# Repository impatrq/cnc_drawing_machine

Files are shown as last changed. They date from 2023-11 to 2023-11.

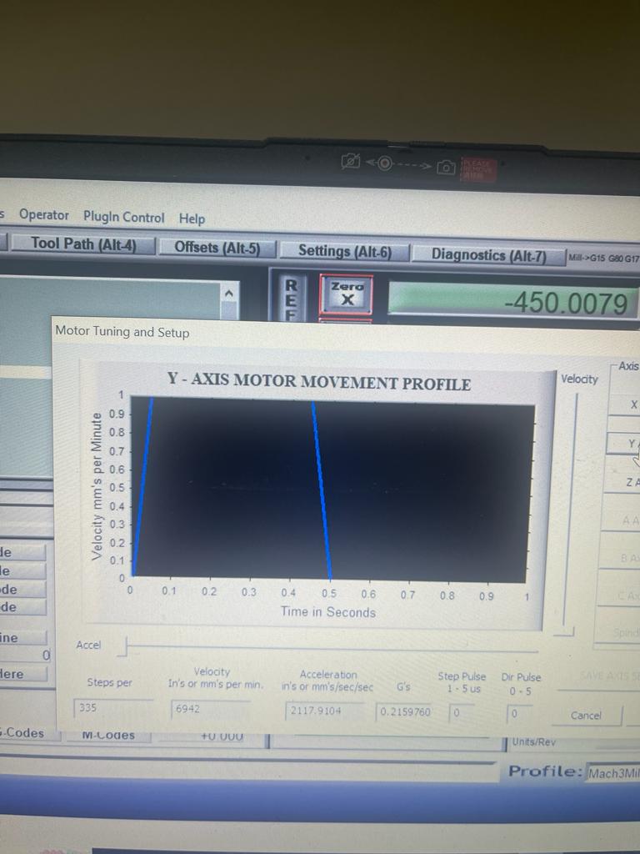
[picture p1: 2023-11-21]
Calibracion Motores Mach3/eje_y_calibration.jpg

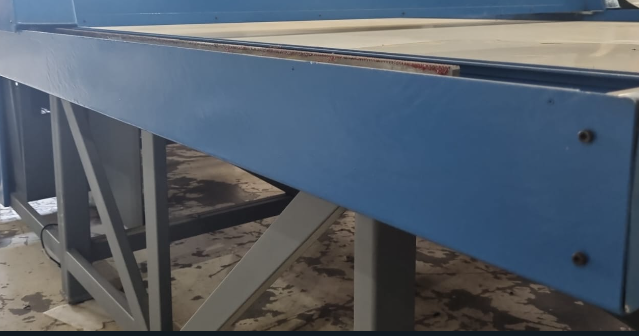
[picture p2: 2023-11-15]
Restauración/Proteccion de Rieles/PLACAS POSTERIORES DE RIELES RESTAURADAS.png

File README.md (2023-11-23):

<div align="center">

# CNC Miliing Machine 



<div align="left">

| Contactanos |
|------------|
|Email: cncproject2023@gmail.com |
|Instagram: cnc_project23 |
|LinkeDIn: Cnc Milling Machine Impa 2023 |
|Pagina Web: https://martincabrera162.wixsite.com/cnc-milling-project |

## ¿Qué es CNC?

CNC Milling Machine: CNC significa control numerico por computadora, es decir que es capaz de medir, automatizar y controlar sus propios procesos, esta siendo una Maquina el cual su obejtivo es cortar, grabar y fresar en madera y aluminio

## Como funciona CNC

El funcionamiento de la CNC es un proceso simple de entender pero a su vez complejo, este tiene como base el programa Mach3, subimos un archivo tipo DXF y R12 el cual, se puede llegar a vizaulisar en el progama como se veria, una vez subida la imagen, solo se debera configurar los limite o punto 0, una vez concretado el punto el progama se encarga de dar las instrucciones necesarias para el marcado o fresasdo de la maquina, una vez dada la instrucciones la maquina solo se encarga de hacer grabado, cortado o fresado para la imagen puesta.

## Infrastuctura/materiales Utilizados 

La CNC tiene una infraestructura muy resistente y de buena calidad. La mayor parte de la infraestructura estaba en optimas condiciones de uso y con poco rasgos de daños al principio del año cuando iniciamos el proyecto.
La infraeestructura de la CNC esta en su mayoria diseñada por la empresa Zucamor, el soporte hecho de metal solido, la mesa construida tambien por metal, con sus respectivos guias lineales para cada eje.
Nuestro principal trabajo fue la restauracion,deteccion y mantenimiento de partes dañadas, ya se diseñando nuevas partes o la reparacion de estas para su futuro uso. Ademas de darle una nueva vida a la CNC con pintura antioxidante para conservar su color y darle una nueva cara a la maquina.

## ¿Quienes somos?

Somos un grupo de alumnos de E.E.S.T. N°7 "Taller Regional Quilmes" (IMPA) de la Especialidad de Tecnico Avionico

### Cejas ramiro agustin

DNI: 46.030.174 

✆ 11 5946-8614

--> 📧 Ramiroagustincejas@gmail.com

Linkedin: www.linkedin.com/in/ramiro-cejas-20350629a

### Cabrera martin tadeo 

DNI: 45.812.906 

✆ 11 2260-3241

--> 📧 martincabrera14@hotmail.com

Linkedin: https://www.linkedin.com/in/martin-cabrera-2213b429a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

### Amarilla Joaquin 

DNI: 46.701.344 

✆ 11 4400-3314

--> 📧 joa.amarillos@gmail.com

Linkedin: https://www.linkedin.com/in/joaquin-amarilla-906a54173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

### Comisso Valentin

DNI: 46.428.455 

✆ 11 5931-8106

--> 📧 comissovalentin@gmail.com

Linkedin:

### Di virgilio Ivan

DNI: 46.740.367 

✆ 11 5812-7218

--> 📧 diviiva02@gmail.com

Linkedin: https://www.linkedin.com/in/ivan-di-virgilio-05bb202a0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

### Romero Tomas 

DNI: 46.904.673 

✆ 11 2158-7226

--> 📧 rometomy@gmail.com

Linkedin: https://www.linkedin.com/in/tomas-romero-a1938329a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

<div align="center">
 


 ## Como Contactarnos

<div align="left">

* 📧 Email: cncproject2023@gmail.com

* 🌐 Página Web: https://martincabrera162.wixsite.com/cnc-milling-project

* 📷 Instagram: @cnc_project23

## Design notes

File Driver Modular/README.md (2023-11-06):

## Configuracion del Driver Modular Tb6600

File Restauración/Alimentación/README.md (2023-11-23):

# Un antes y despues del gabinete con el circuito adentro

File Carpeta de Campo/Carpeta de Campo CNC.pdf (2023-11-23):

### Carpeta de campo

(Resumen de las cosas hechas día por día)

Participantes del proyecto CNC (Control Numérico por Computadora):

Martin Cabrera

Ivan Divirgilio

Tomas Romero

Ramiro Cejas

Joaquín Amarilla

Valentín Comisso

Dia 20 de marzo: Se nos dio el proyecto en el estado el cual nosotros debíamos cambiarlo, para esto en el mismo día movimos entre todos los participantes del proyecto, algunos profesores y otros alumnos el proyecto a una zona el cual podíamos estar más al alcance como también era más visible.

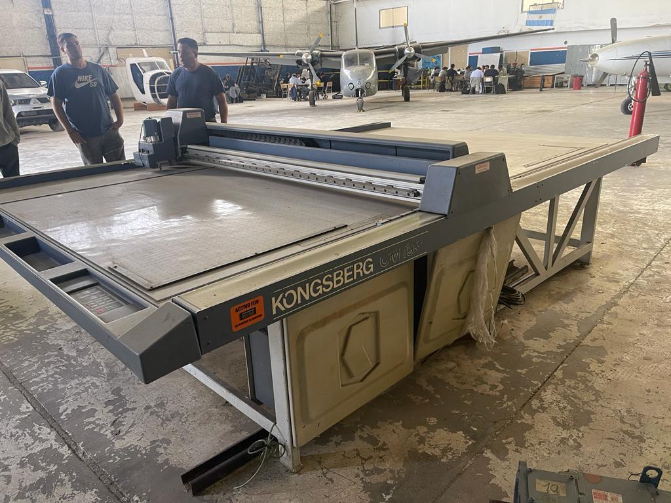
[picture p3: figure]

Semana del 20 hasta 27 de marzo: Se revisó la máquina de punta a punta, viendo que era lo que servía del proyecto, como los cables, las correas, los servos motores, las correderas o la estructura de la máquina y ver si no estaba quemado o en mal estado. Nos percatamos de que el equipo que poseía la maquina estaba muy desgastado, desactualizado y sin uso desde hace mucho.

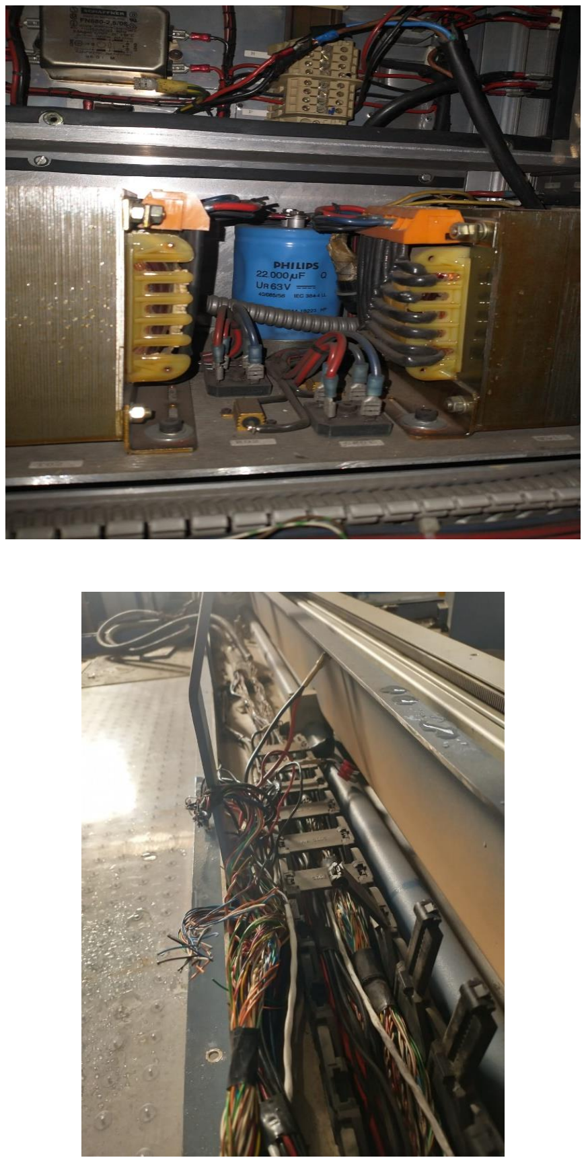
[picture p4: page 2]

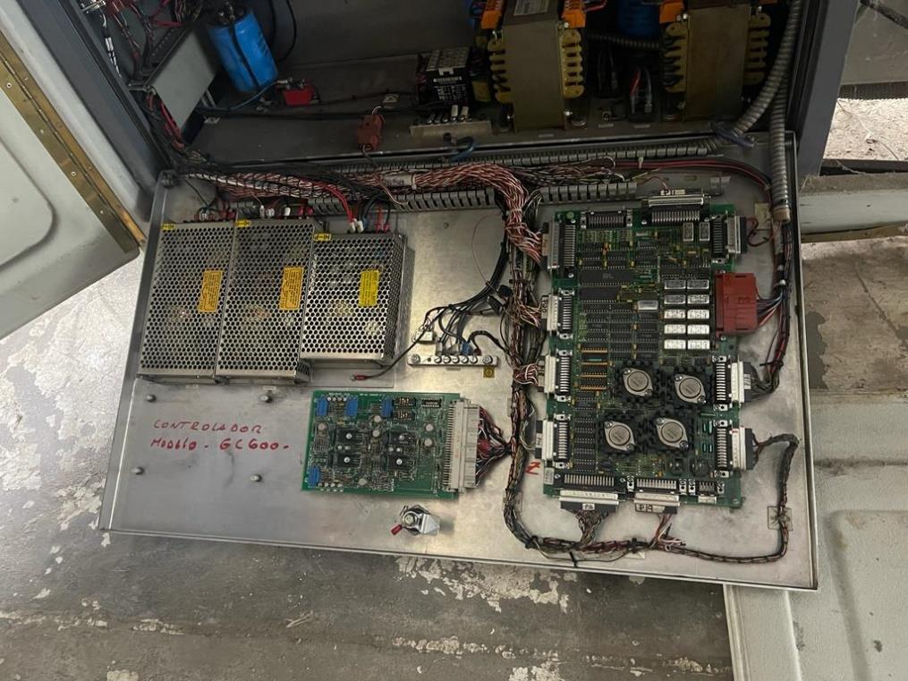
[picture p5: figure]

Dia 28, 29 y 30 de marzo: Se investigó bien cada material que teníamos en buen estado, buscando su datasheet, y toda propiedad de los materiales, para ver si cada cosa era compatible una con la otra, y si se necesitaba cambiar o agregar cosas. La investigación consistió en buscar la datasheet de los motores y sus drivers, como también si los paso a paso que tenían eran compatibles.

Dia 4 y 5 de abril: Se investigó sobre los softwares que se podían utilizar para los motores que necesitábamos, y ver si estos eran compatibles con los drivers que requeríamos.

Dia 11, 12 Y 13 de abril: Investigación sobre los encoder y sus señales de salida y, de entrada, al igual que sus motores, aunque por más que teníamos el encoder, decidimos comprar un paso a paso tanto por los beneficios y por qué el encoder tenía desperfectos que perjudicaban bastante al motor.

Dia 18, 19 y 20 de abril: Se investigó sobre los sensores que tenía la máquina, uno de los sensores que nos llamó la atención fueron los sensores sick, estos sensores de contraste eran una de las implementaciones que queremos poner.

Dia 25, 26 y 27 de abril: Se probó el motor para ver si recibía y funcionaba al 100%, como también visualizamos el conexionado de los drivers al rotor y estator de este mismo.

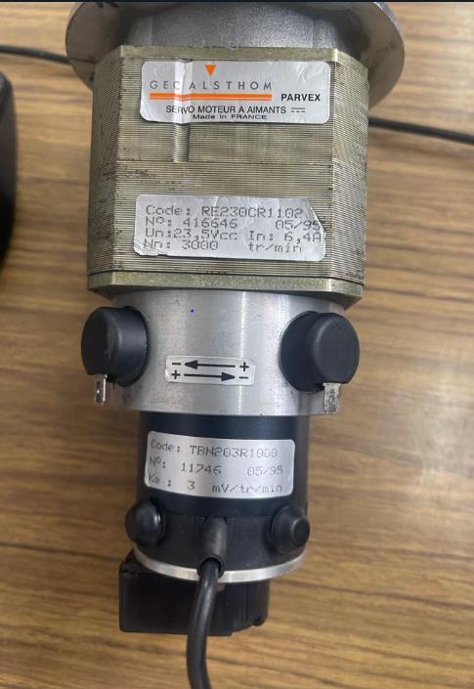
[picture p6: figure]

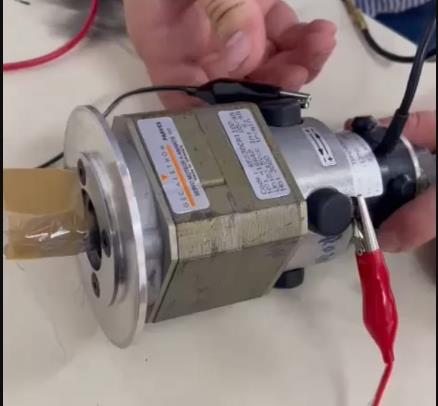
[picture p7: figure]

Dia 2, 3 y 4 de mayo: Nos comprometimos a trabajar de manera más eficiente con el proyecto por lo tanto ordenamos y limpiamos cada parte de la maquina como lo son los ejes, la base, donde se encontraba la parte electrónica y los rieles para que no haya inconvenientes, y se vio más a profundo si tenía un desperfecto las correderas, ejes o algún conexionado interno, además de remover las partes abolladas de la máquina para próxima restauración.

Dia 9, 10 y 11 de mayo: Se removió el del eje Z, para examinar parte rotas o algún desperfecto, para después repáralo y mejorarlo. El eje Z anteriormente al pertenecer a sucamor estaba especializado en cortar cartón, por lo tanto, este presentaba un cúter y en otro espacio del eje también había una rueda que lo ayudaba a cortar y movilizarse. Debido a que el eje z estaba en completo disfuncionamiento y en estado de oxido se empezó a diseñar una nueva forma de poder cumplir con el objetivo principal el cual era trabajar con madera, aluminio y/u otros materiales.

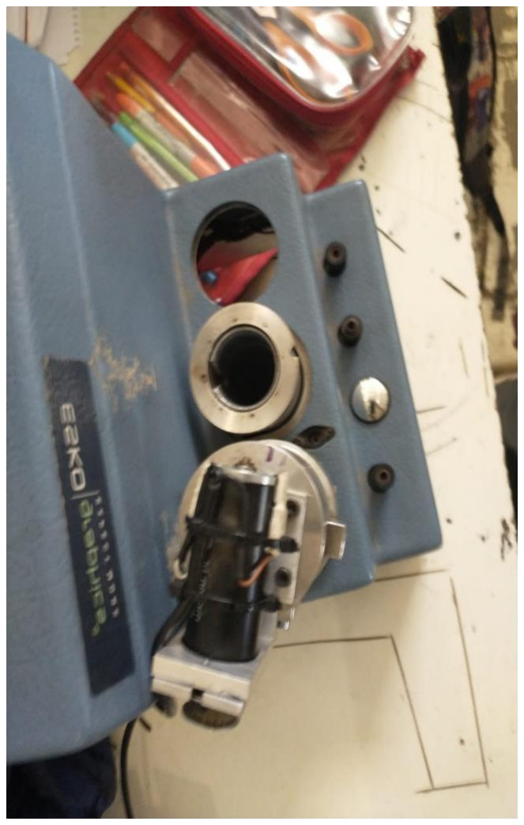
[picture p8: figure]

feature/XX/agregar-hola-mundofeature/XX/agregar-hola-mundo

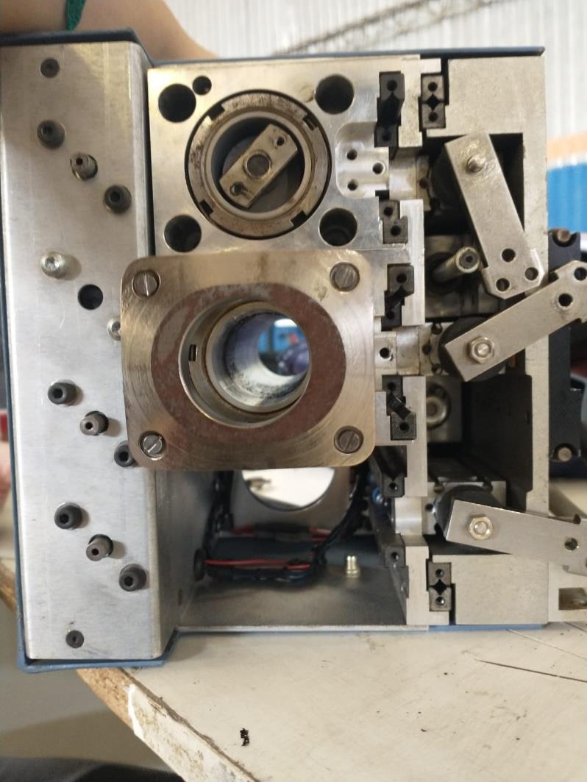
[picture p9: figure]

Día 16, 17 y 18 de mayo: Se investigó sobre los nuevos motores como drivers a usar y si estos eran compatibles entre sí, como la investigación de programa a usar para el movimiento de los motores

Dia 23 y 24 de mayo: Se compraron los drivers y los motores paso a paso, para después probarlos y ver que funciones correctamente.

Dia 30, 31 y 1 de mayo/junio: Pusimos en prueba la fuente que estaba en la máquina, la cual no funcionaba el regulador de voltaje y una estaba en condiciones deplorables.

Dia 14 y 15 de junio: Examinación de las partes dañadas después de la reparación y engrasamiento del eje Y.

Dia 21 y 22 de junio: Búsqueda y prueba de las aplicaciones para los drivers y para las órdenes de los motores, y esta debía ser compatible como también gratis.

Dia 28 y 29 de junio: Visualización del color de la pintura que íbamos a usar, y la compra de aquella, como también la compra de utensilios para lograr este objetivo.

Dia 5 y 6 de julio: Se lijó la pintura sobrante anterior y las partes oxidadas que estaban presentes, como también se desarmo devuelta todas las piezas para próximo acondicionamiento estético.

Dia 12 y 13 de julio: Se pintó todas las partes externas e interna y la base de la CNC y también se midió un estimado en metros de cuantos cables debíamos usar para la conexión completa de toda la máquina.

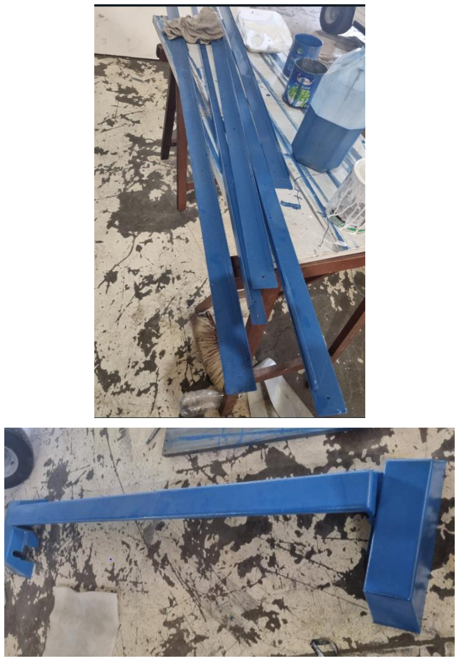
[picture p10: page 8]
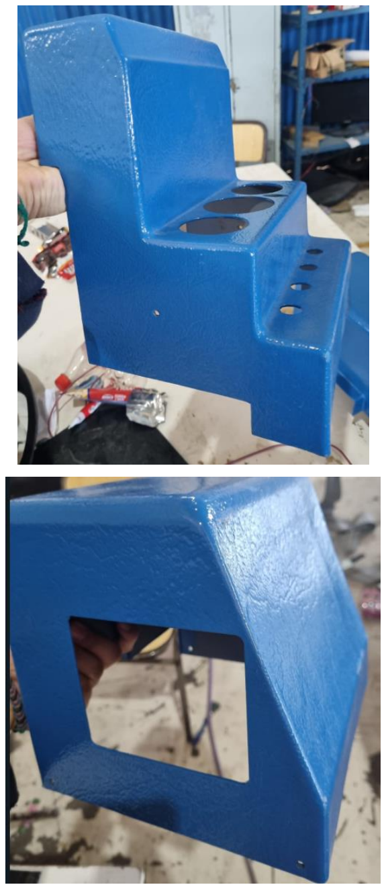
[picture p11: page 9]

Dia 2 y 3 de agosto: Empezamos a colocar los drivers en el gabinete para ordenar donde iría cada cosa en su lugar, y también empezamos a pasar los cables para el conexionado de la máquina, como también enlazamos los motores a cada eje, para visualizar que todo tenga un espacio justo.

Dia 9 y 10 de agosto: Se hizo el diseño 3d de los soportes de los motores, para mejor estabilidad entre el motor y el paso a paso, se terminó el cableado los ejes, se compró la fresadora a usar.

Dia 16 y 17 de agosto: Se imprimió el diseño 3D de los soportes para los motores y se ensambló al motor con el paso a paso y se probó para corroborar que todo esté en perfectas condiciones.

Dia 22, 23 y 24 de agosto: Con los materiales que teníamos guardado hicimos la nueva fuente como también se probó con la otra fuente para garantizar que nada esté en corto y que no tenga algún desperfecto, se instaló los drivers y la plaqueta de desarrollo para comprobar su funcionamiento.

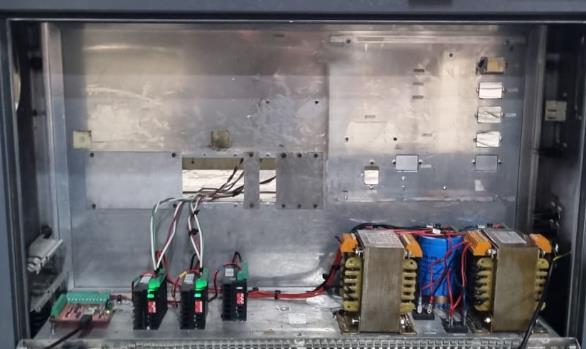
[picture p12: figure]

Dia 29, 30 y 31 de agosto: se compró la pintura para la base superior de la CNC y se diseñó el soporte de los cables, mientras tanto se empezó a diseñar cómo iba a ser el soporte del eje Z conectado con la fresadora.

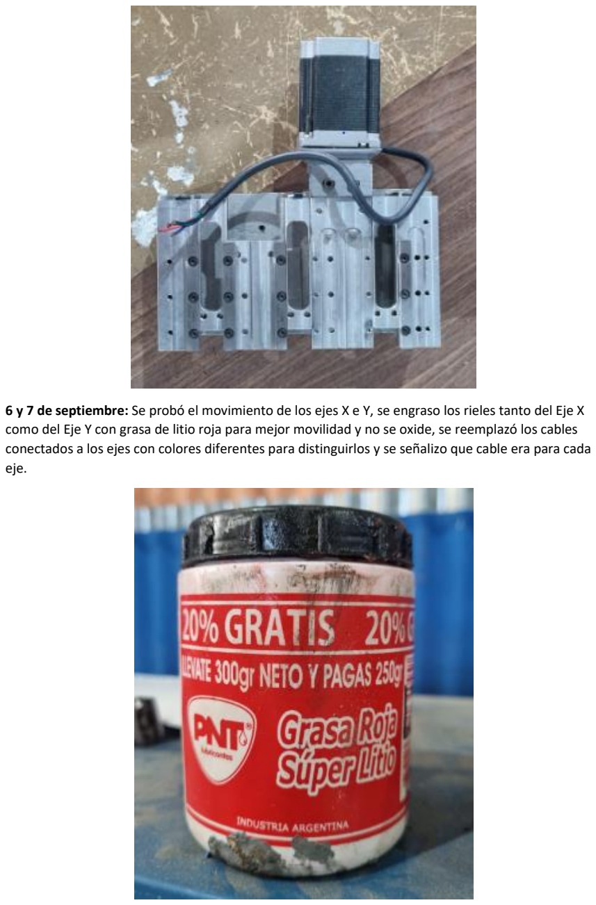
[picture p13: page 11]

6 y 7 de septiembre: Se probó el movimiento de los ejes X e Y, se engraso los rieles tanto del Eje X como del Eje Y con grasa de litio roja para mejor movilidad y no se oxide, se reemplazó los cables conectados a los ejes con colores diferentes para distinguirlos y se señalizo que cable era para cada eje.

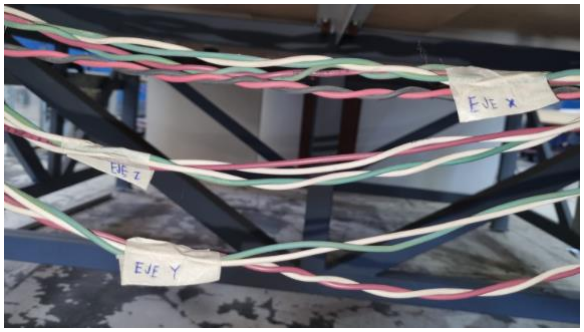
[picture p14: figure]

Dia 12, 13 y 14 de septiembre: Se colocó una corredera para los cables que sobresalen de la CNC y que van conectados a los ejes, para que no se enreden y se le colocó un soporte a la corredera para que esta no haga un esfuerzo innecesario.

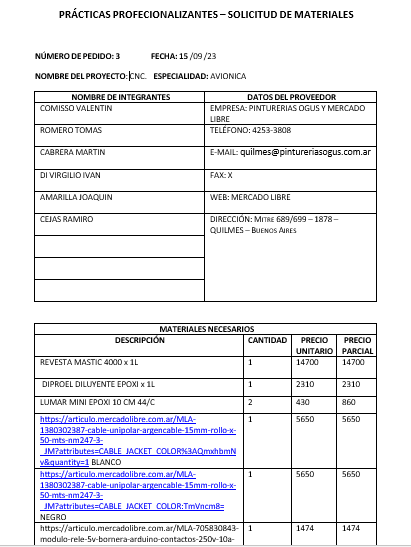
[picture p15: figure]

Dia 19, 20 y 21 de septiembre: Se probó la fresadora y se modificó para el funcionamiento con el eje z sin la necesidad de prender la a mano y haciendo la parte del circuito.

Dia 3, 4 y 5 de octubre: Se hizo la prueba de botón de parada de emergencia y una vez probado se armó el sistema conectado al circuito para que este funcione correctamente. El soporte del eje Z se había terminado y se probó la resistencia con el peso que podría llegar a exigir la fresadora.

Dia 10,11 y 12 de octubre: Se diseñó la estructura de los fines de carrera, y se removió el patín del eje X debido a que los rulemanes estaban, en su mayoría, oxidados, se guardaron todas las piezas para próxima restauración.

Dia 17, 18 y 19: Se instaló el eje X y se limpió y se engraso, para que el eje Z se implemente al soporte del eje X, y a su vez la fresadora se colocó en el eje Z, se hizo todo el conexionado del eje Z, y se probó su funcionamiento.

Dia 24, 25 y 26: Se calibró todos los ejes, se probó su funcionamiento con distintas figuras, y se comprobó que la fresadora haga bien su trabajo, el cual era fresar y marcar las figuras que se le imponga. Hubo un percance con los bolitas de los rule manes que permitían la movilidad del Eje X, los cuales se oxidaron por goteras arriba del proyecto que termino oxidando el proyecto. Debemos cambiar las bolitas y revidar el patín del Eje X para poder recuperarlo y seguir con el proyecto.

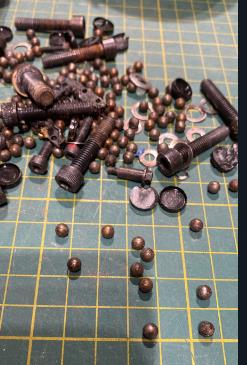
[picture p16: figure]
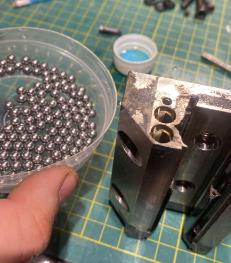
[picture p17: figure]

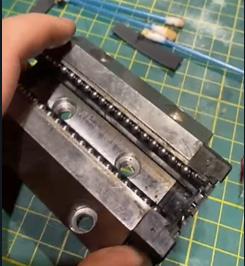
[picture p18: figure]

Dia 31 de octubre y 1 de noviembre: Se compro y reemplazo las bolitas de los rule manes que anteriormente estaban oxidadas. Con esto arreglado y el Eje X instalado nuevamente, se sigue probando el funcionamiento de la CNC y de todos sus ejes con más diseños subidos al programa tanto en madera como aluminio con distintas mechas en la fresadora. También se diseñó una carcasa para poder ocultar el eje z e intentar insonorizarla por el ruido que genera al trabajar.

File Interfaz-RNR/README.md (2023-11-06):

# interfaz de control RNR

La Interfaz RNR de 4 ejes es una placa de control robusta y versátil, diseñada para la automatización de máquinas robóticas y sistemas de control numérico computarizado (CNC)

En las imagenes se proporcionara informacion de la placa, sus posibles conexiones y imagenes detalladas de la misma.

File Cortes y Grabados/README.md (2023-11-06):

# aca se mostraran todos los cortes & grabados que vamos haciendo

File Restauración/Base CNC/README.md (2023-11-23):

# Fotos de la restauracion de la Base del CNC

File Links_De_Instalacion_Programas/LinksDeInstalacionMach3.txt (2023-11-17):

link al video de instalacion de mach3 e lazycam incluido:

https://www.youtube.com/watch?v=nM6qbjCr8SA

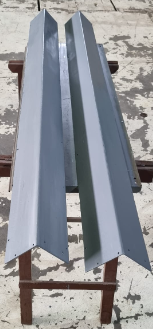
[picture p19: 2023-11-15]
Restauración/Proteccion de Rieles/PLACAS POSTERIORES DE RIELES.png

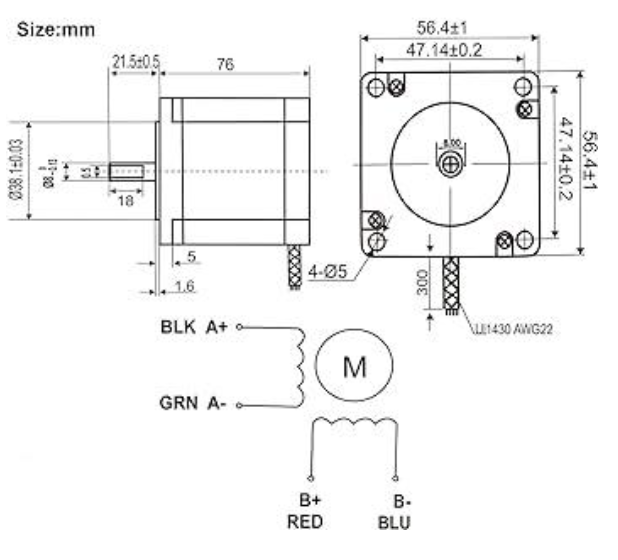
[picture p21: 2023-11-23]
Servo-Motores y Paso a Paso/DIseño de estructura del motor nema 23.PNG

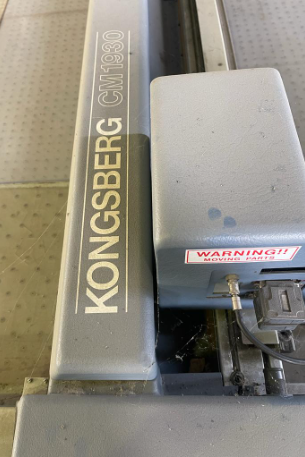
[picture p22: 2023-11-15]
Restauración/Carcasa_eje_x/CARCASA PROTECTORA DEL DE PASO A PASO EJE X.png

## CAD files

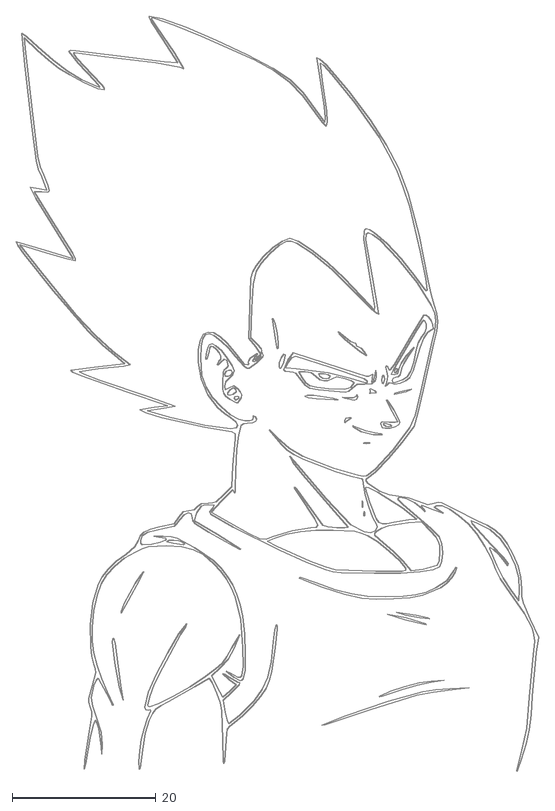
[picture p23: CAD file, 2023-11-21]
Dibujos_dxf/goku.dxf
72.6 x 104.9

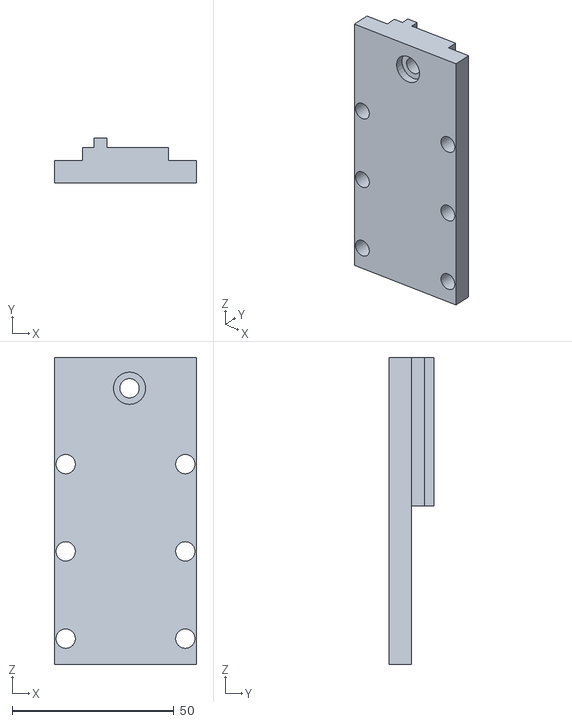
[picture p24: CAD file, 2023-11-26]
eje z/Soporte_Frezadora_Eje_Z.stl
44.0 x 14.0 x 95.0

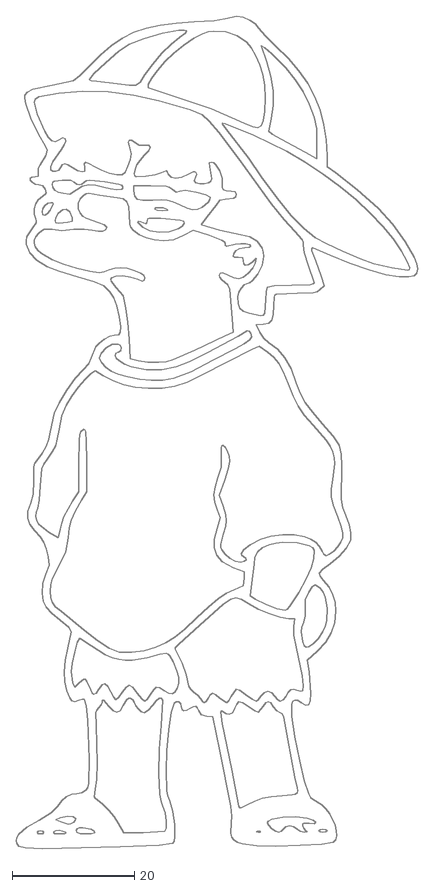
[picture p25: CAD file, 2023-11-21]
Dibujos_dxf/lisa.dxf
65.6 x 136.0

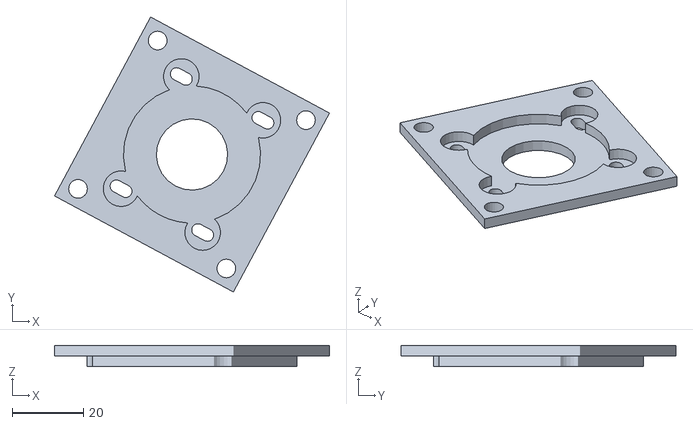
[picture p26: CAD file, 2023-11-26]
eje z/segundo_acople_pasopaso_eje_z_CIRCULOS_AMPLIADOS.stl
77.2 x 77.2 x 6.00

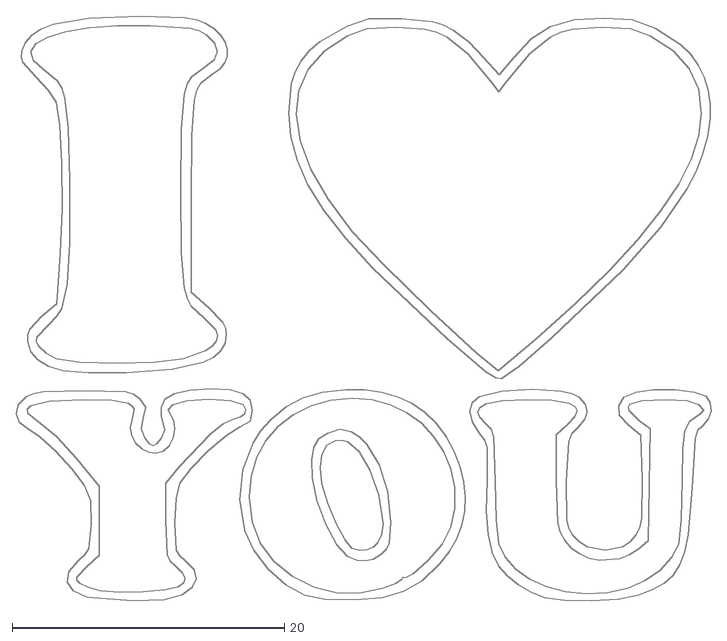
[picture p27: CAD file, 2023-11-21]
Dibujos_dxf/love.dxf
51.1 x 43.0

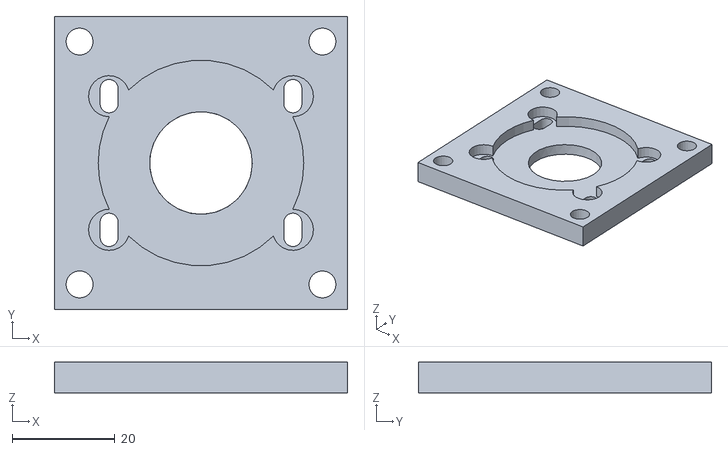
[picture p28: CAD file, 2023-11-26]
eje z/segundo_acople_pasopaso_eje_z_definitive_edition.stl
57.0 x 57.0 x 6.00

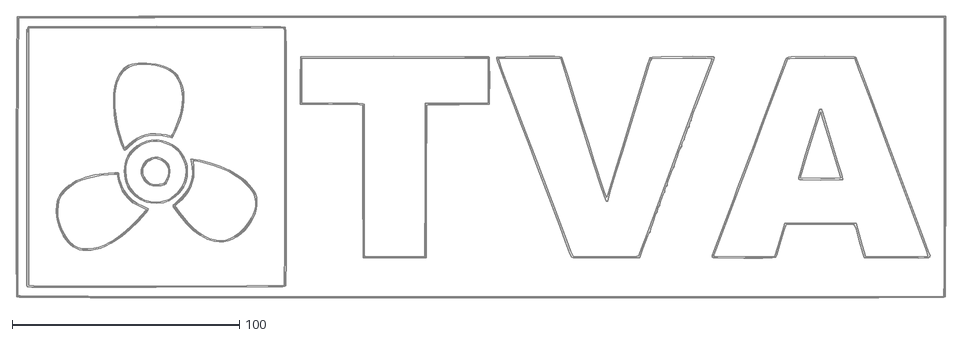
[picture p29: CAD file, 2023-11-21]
Dibujos_dxf/logotunellllll.dxf
409.2 x 124.0

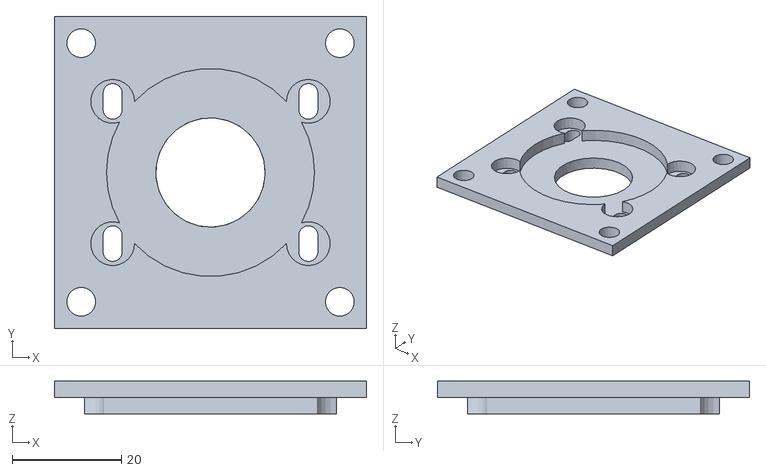
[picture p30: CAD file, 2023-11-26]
eje z/pieza.stl
57.0 x 57.0 x 6.00

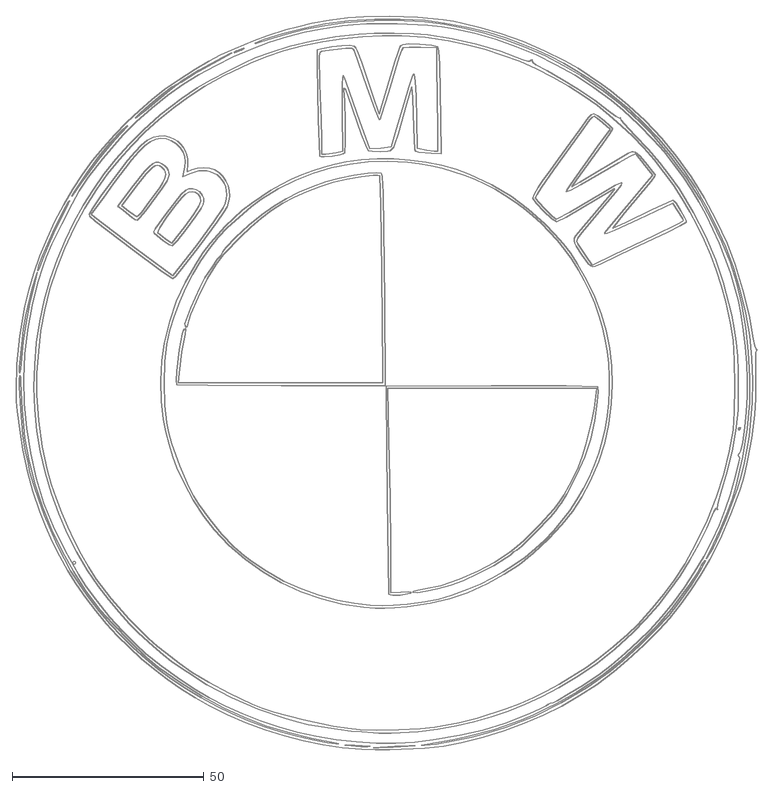
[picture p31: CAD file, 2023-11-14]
Dibujos_dxf/bmw.dxf
193.3 x 191.4

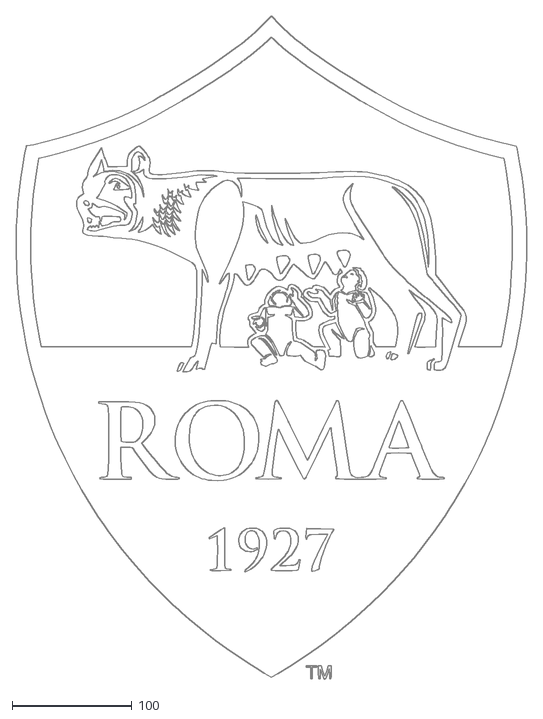
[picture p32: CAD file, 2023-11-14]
Dibujos_dxf/Roma-Logo-2013.dxf
427.1 x 554.5

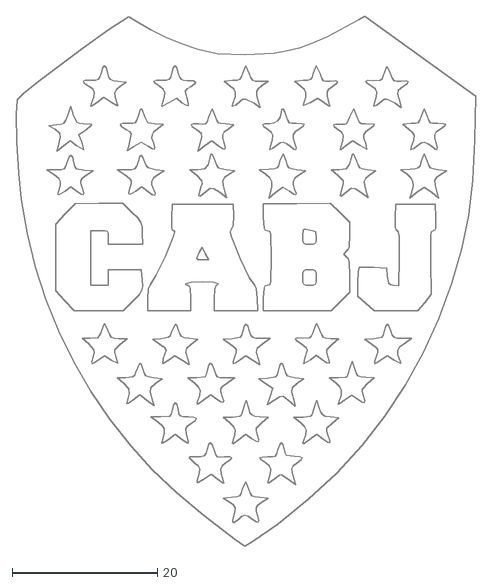
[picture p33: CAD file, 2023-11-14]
Dibujos_dxf/boca.dxf
63.2 x 73.0

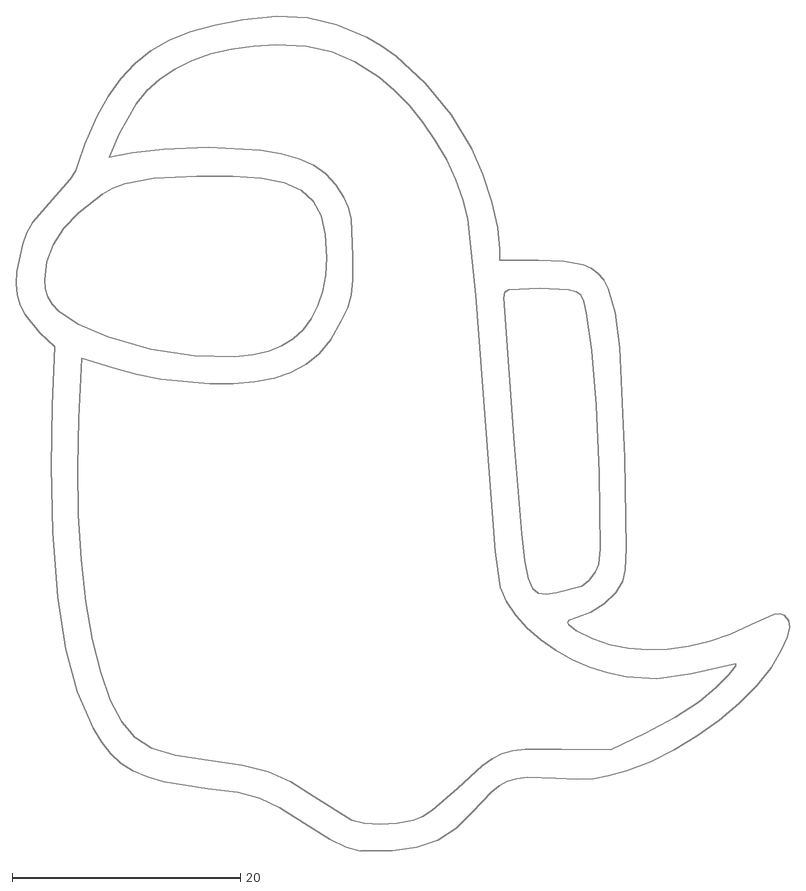
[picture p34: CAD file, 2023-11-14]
Dibujos_dxf/among.dxf
67.7 x 73.1

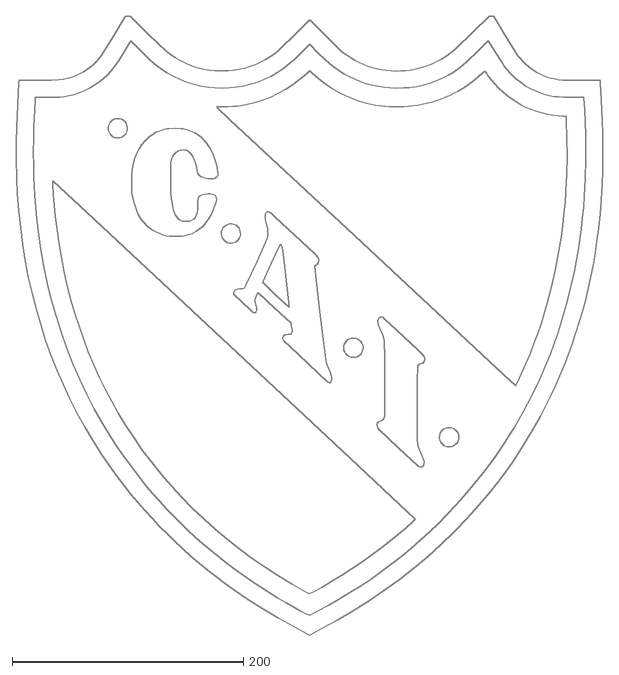
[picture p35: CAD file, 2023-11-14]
Dibujos_dxf/Escudo_del_Club_Atlético_Independiente.dxf
507.4 x 535.5

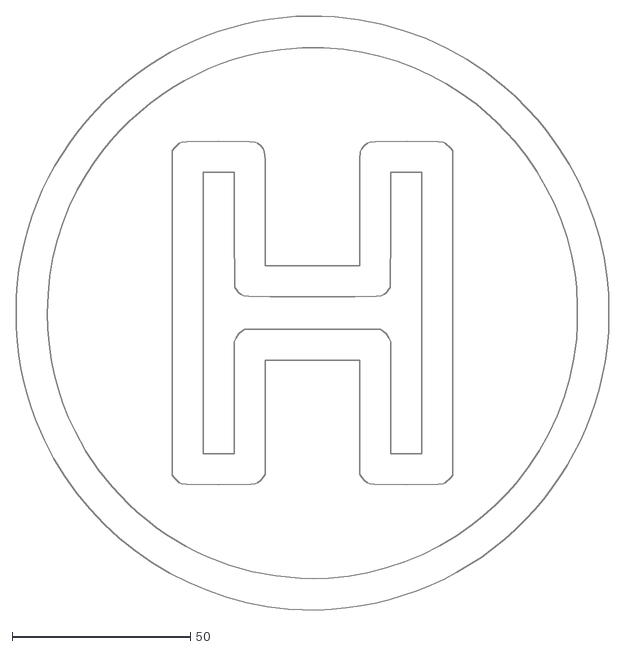
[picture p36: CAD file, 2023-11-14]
Dibujos_dxf/helipuerto.dxf
166.3 x 166.6

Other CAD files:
Dibujos_dxf/butters.dxf
Dibujos_dxf/cara.dxf
Dibujos_dxf/casco.dxf
Dibujos_dxf/flash.dxf
Dibujos_dxf/Escudo_de_Racing_Club.dxf
Dibujos_dxf/avengers.dxf
Dibujos_dxf/cartman.dxf
Dibujos_dxf/copa del mundo.dxf
Dibujos_dxf/dragon.dxf
Dibujos_dxf/flu.dxf
Dibujos_dxf/ghostbusters.dxf
Dibujos_dxf/homer.dxf
Dibujos_dxf/impa.dxf
Dibujos_dxf/impa2.dxf
Dibujos_dxf/inter.dxf
Dibujos_dxf/jordan.dxf
Dibujos_dxf/nike.dxf
Dibujos_dxf/pika.dxf
Dibujos_dxf/porche.dxf
Dibujos_dxf/quito.dxf
Dibujos_dxf/sony.dxf
Dibujos_dxf/spreen.dxf

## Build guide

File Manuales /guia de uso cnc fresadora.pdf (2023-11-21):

# guia de uso cnc fresadora

1- tener instalado los programas: inkscape, lazycam, mach3

2- abrir y inicializar un dibujo en inkscape, abrimos donde dice documento nuevo

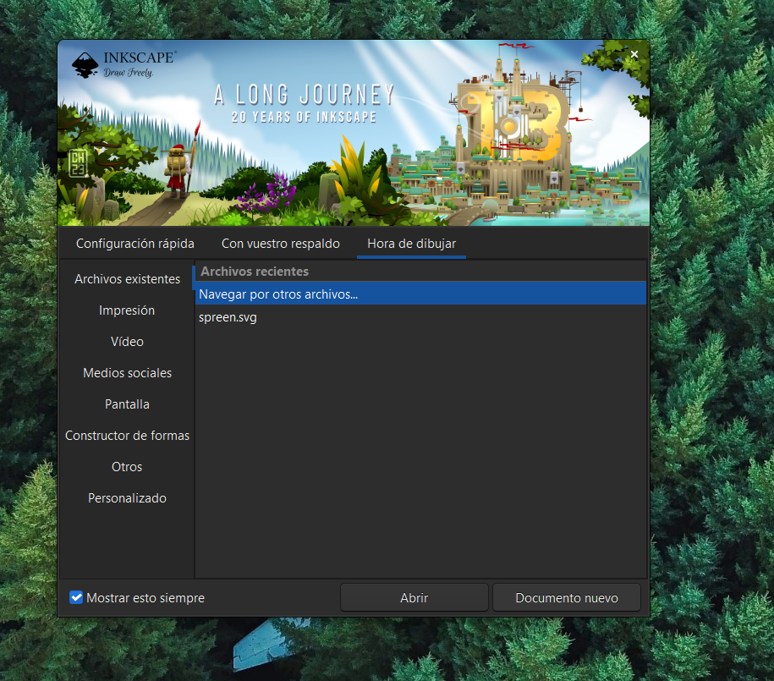
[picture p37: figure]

3- nos dirigimos a donde dice archivo.

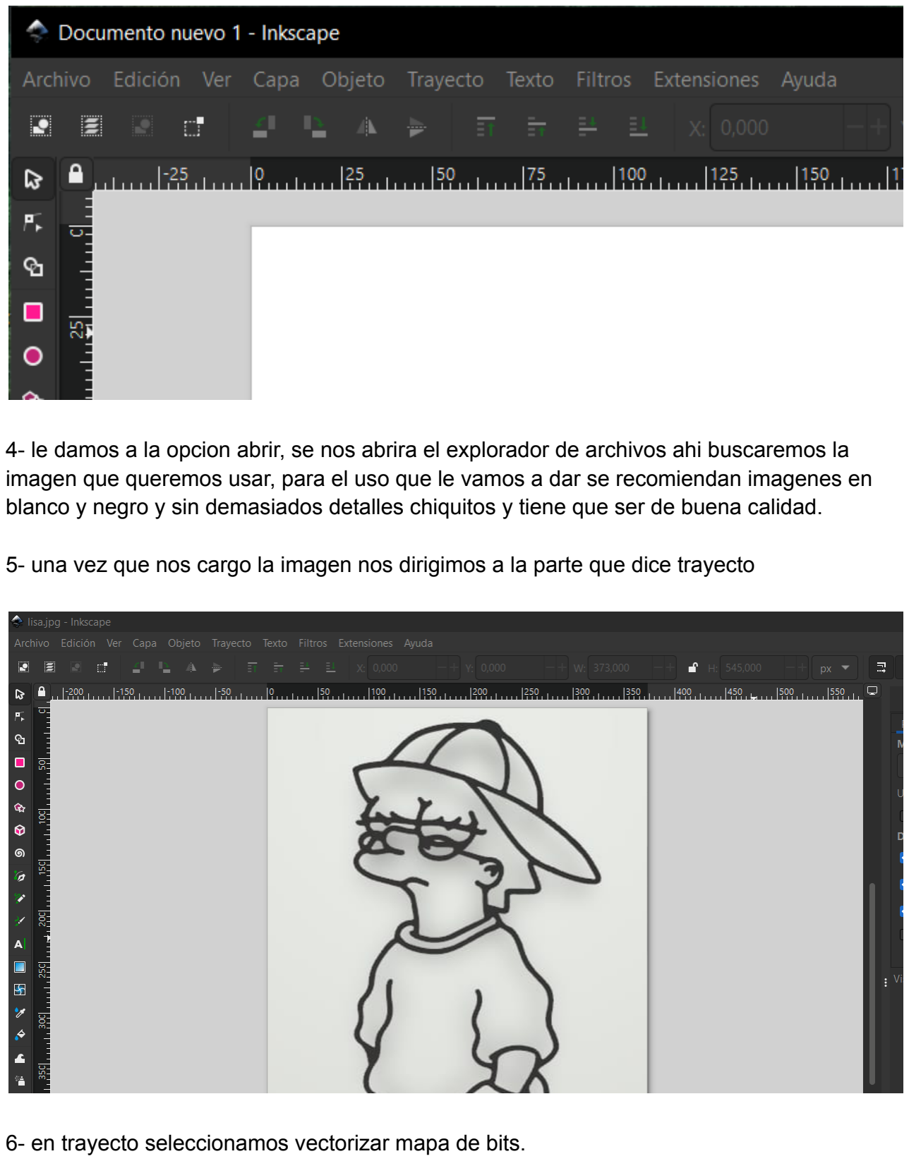
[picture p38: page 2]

4- le damos a la opcion abrir, se nos abrira el explorador de archivos ahi buscaremos la imagen que queremos usar, para el uso que le vamos a dar se recomiendan imagenes en blanco y negro y sin demasiados detalles chiquitos y tiene que ser de buena calidad.

5- una vez que nos cargo la imagen nos dirigimos a la parte que dice trayecto

6- en trayecto seleccionamos vectorizar mapa de bits.

7- se nos abrira esta parte aca seleccionamos entre tres modos de deteccion el q mas nos convenga para vectoriazar nuestra imagen.

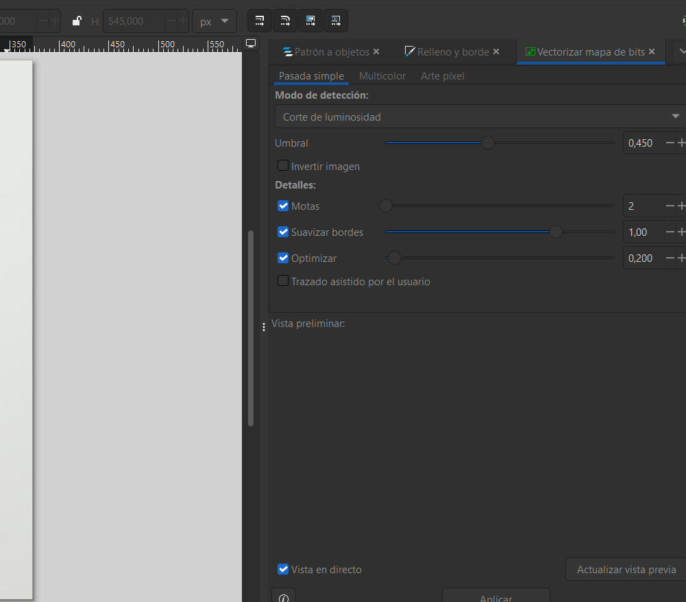
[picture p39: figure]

8- para saber que modo nos conviene mas realizamos una vista previa para esto solo haría falta hacer click en la imagen

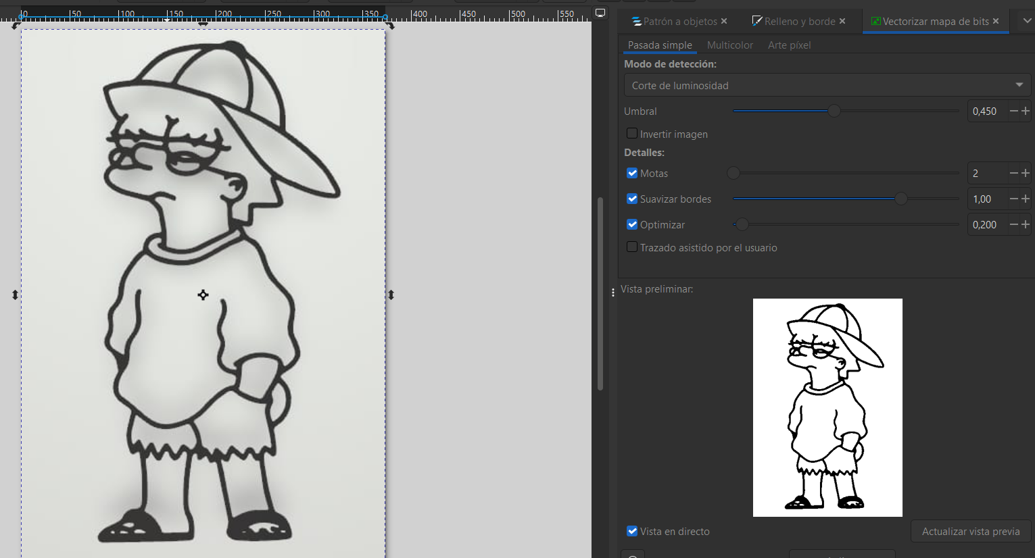
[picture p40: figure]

9- en este caso tanto el modo de detección como el el umbral son correctos, ya que para que la imagen tenga una buena vectorizacion en la vista previa deberia verse asi. con el umbral lo que hacemos es intensificar las lineas y el color, a veces puede pasar o que un dibujo se vea demasiado oscuro y no se puedan diferenciar las lineas o que se vea demasiado claro y no se reconozcan las lineas, para resolver esto existe el umbral.

10- una vez seleccionado el modo y vemos que esta bien la imagen le damos a aplicar.

11-una vez aplicado se nos desaparecera la imagen en vista previa y veremos que tenemos una imagen identica a la nuestra encima de la vieja imagen, esa imagen nueva es la vectorizada, para diferencia una de la otra lo que tenemos que hacer es hacer click, si a la hora de hacer click se nos actualiza la vista previa entonces es la imagen original sin en cambio al hacer click no nos aparece nada en donde iria la vista previa entonces es la imagen vectorizada.

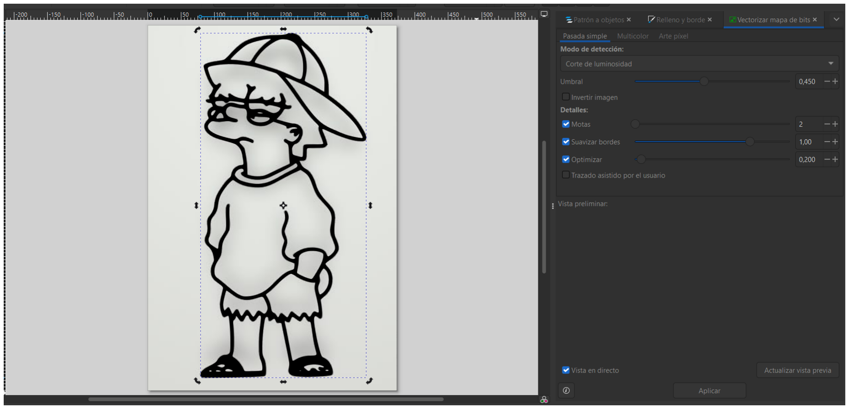
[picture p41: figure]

12- lo siguiente que hacemos es seleccionar la imagen original que no esta vectorizada y la borramos con clik derecho cortar o suprimir. tengan mucho cuidado de no borrar la imagen vectorizada. una vez borrada la imagen original , vamos devuelta a archivo luego a guardar como y colocamos el nombre del dibujo y en tipo de archivo lo tenemos que poner como dxf r12, es muy importante ponerlo asi sino lazycam no lo reconocera.

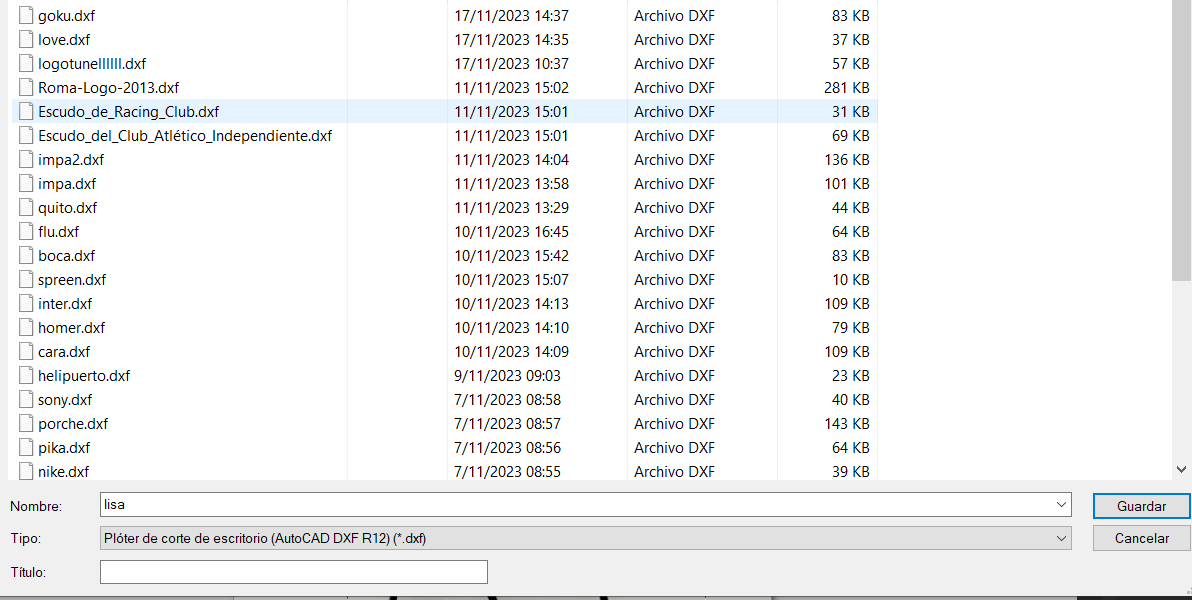
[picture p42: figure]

12- ahora finalizamos con inkscape y pasamos a lazycam, una vez abierto el programa vamos a donde dice dxf y se nos abrira el explorador de archivos, una vez abierto buscamos nuestro dxf y lo abrimos.

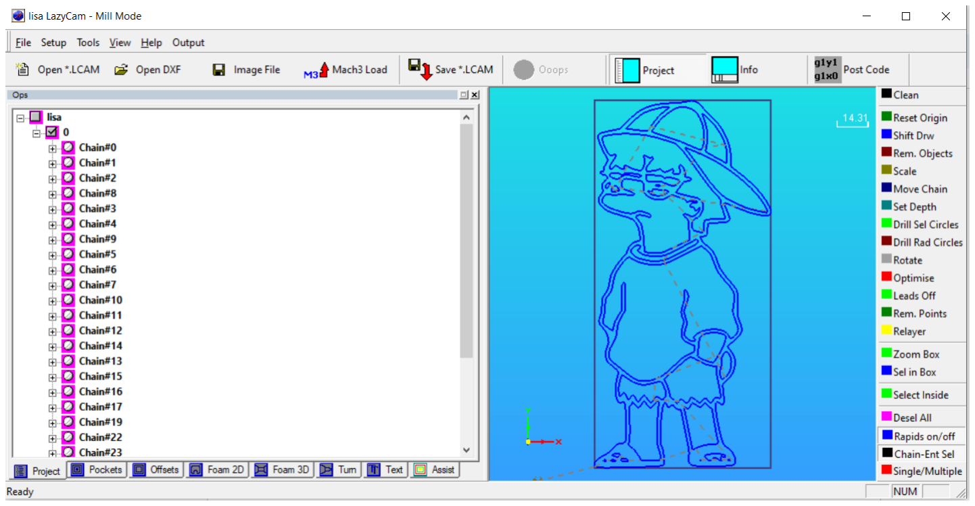
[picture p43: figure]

13- cada chain es una parte del dibujo, al mantener sobre una chain la podemos borrar o cambiar de orden.

14- los botones que se encuentran a la derecha nos permiten modificar algunas cosas los mas utilizados son, scale y optimise, scale nos dejamos ajustar el tamaño del dibujo solo pudiendo ajustar el eje x ya que el y se ajusta automaticamente a la proporcion que le dimos con el x, luego tenemos optimise este lo que hace es organizar los chains para que el camino que haga la fresa a la hora de cortar sea el mas optimo aunque como dije esto luego lo podemos cambiar nosotros a como mas nos guste.

15- una vez scalamos el dibujo y le dimos a optimise (esta ultima es opcional), vamos a donde dice info y hacemos click.

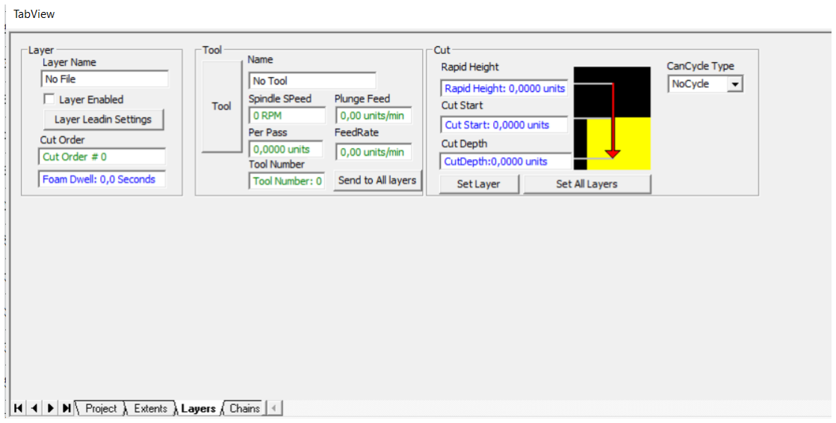
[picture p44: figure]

se nos abrira abajo una seccion, en esa seccion vamos a donde dice layer y le damos click

16- en layers tenemos la seccion cut: aca seleccionamos rapid height: cuanto va a subir la mecha cada vez que vaya de un chain a otro, siempre poner entre 3 e 5 milimetros, asi nos aseguramos que la mecha cuando se mueva a otro chain no choque con nada, luego tenemos el cut start en este indicamos a que altura iniciar el corte siempre dejarlo en 0 ya que es la altura a la que dejamos la mecha nosotros, por ultimo esta cut depth aca indicamos la profundidad del corte que queremos, es importante poner siempre un (-) ej: -1,0000.

17- en la parte de tool apretamos y se nos abrira esto:

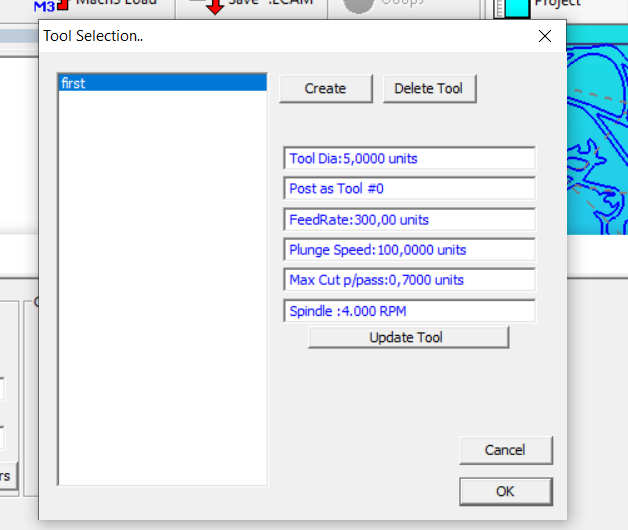
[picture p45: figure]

- aca creamos la herramienta primero en el tool dial ponemos el ancho de la mecha, el feedrate ponemos la velocidad a la que queremos que se mueva la fresadora, el plunge speed es la velocidad a la que la mecha va a perforar, el max cut es cuanto va a bajar la fresa por pasada y en spindle ponemos los rpm. una vez configurada le damos a create nos va a pedir un nombre y luego se guarda y quedaria como en el ejemplo este con (first). una vez creada le damos al ok.

18- una vez tengamos todo configurado le damos tanto en tool como en cut al boton set to all layers esto hara que cada chain tenga la misma configuracion de corte si queremos que en un chain especifico cambie algun dato de la seccion cut solo nos dirigimos a ese chain y luego le damos al boton info luego layers configuramos el layer para ese chain y le damos set layer y solo ese chain tendra esa configuracion.

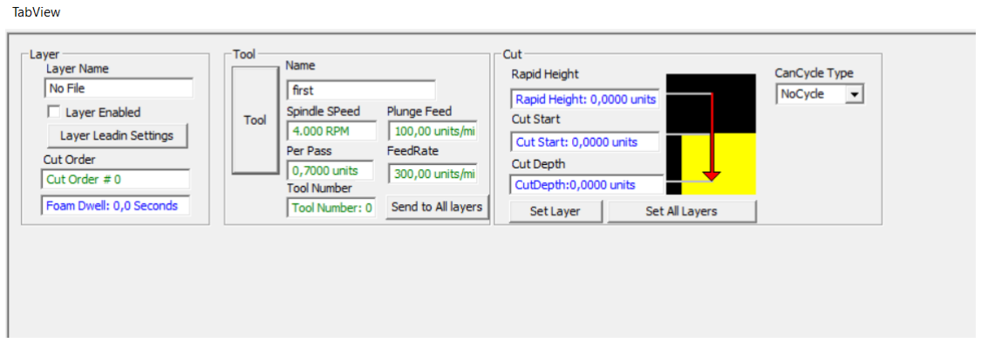
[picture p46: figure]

18- para saber si estan todos los datos bien vamos a la sección chains que se ubica al lado de layers y verificamos los datos, puede pasar que a la hora de ir a chains el z aparezca sin los datos de profundidad y altura bien, para esto solo dale click a otro chain por ejemplo en la imagen estoy en el chain 8 si le das al chain 2 se actualizaran, es importante verificar que todos los chains tengan actualizados los valores puede pasar que un chain no lo tenga aunque este error es raro, por las dudas cambiar tres veces de chain y en cada uno darle al boton set to all layer asi se quedan seguros que todos tengan bien los datos.

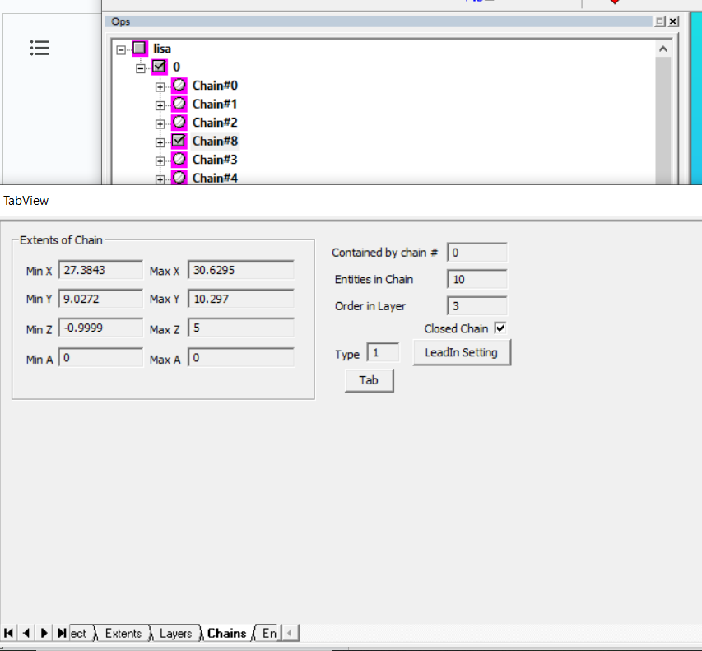
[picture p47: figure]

19- una vez configurado le damos click al boton info se cerrara la seccion y luego le damos a post code , si es la primera vez que lo haces te saldra una ventana grande con algunos datos en este caso unicamente dale a dont show me again y al boton para que se ejecute el post code.

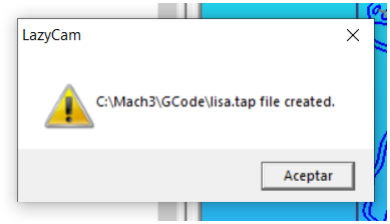
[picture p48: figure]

- una vez creado el archivo te saldria esta ventana aca le damos a aceptar, esta ventana tmb muestra la ubicacion donde se guardan los archivos .tap tambien llamado archivos cam, esta ubicación siempre será la ubicación del programa mach3.

20- una vez creado el archivo tap pasamos a mach3.

21-abrimos la aplicacion mach 3 mill que es para fresado.

22- aca nos dirigimos al apartado que dice load gcode y se nos abrira el explorador de archivos, este se nos abrira en la ubicacion que mach3 guarda los gcodes y donde lazycam tendria q haber guardado nuestro archivo, por lo que al abrir el explorador en esa ubicacion encontraremos nuestro archivo .tap

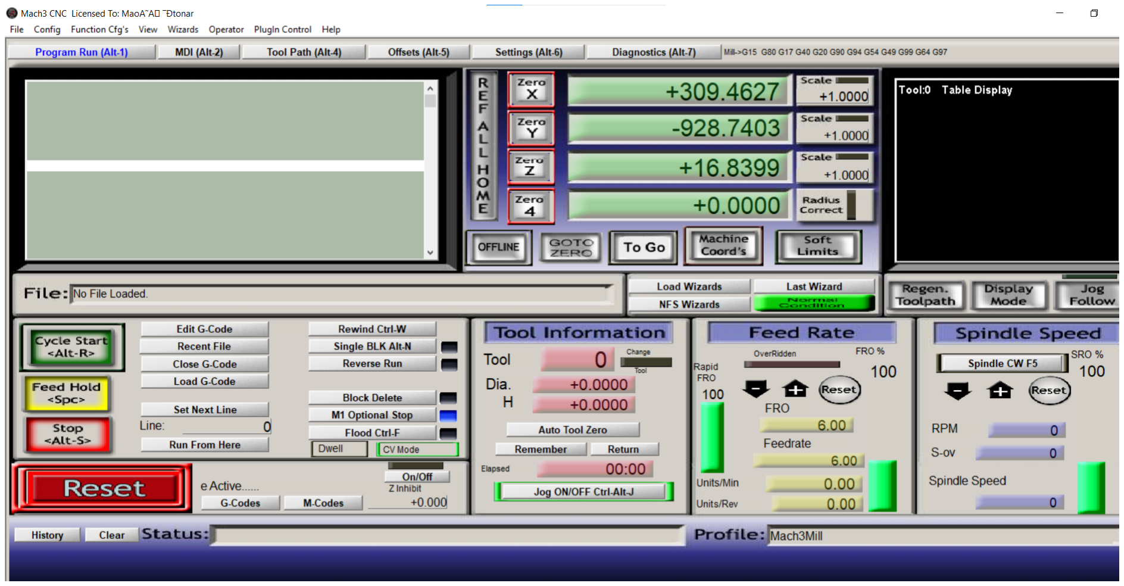
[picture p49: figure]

23-una vez cargado el dibujo ya estaríamos en condiciones de empezar a cortar para esto debemos ya tener calibrado el mach 3 , también debemos ya tener configurado tanto los motores como también la fresadora dentro del programa, si ya tenemos estos pasos realizados solo debemos ubicar la fresa sobre uno de los bordes del material luego ubicamos la mecha sobre el punto 0 del material y ubicamos todos los ejes en punto 0. Para esto apretamos sobre los botones de los ejes y estos automáticamente se pondrán en 0. Es muy importante tener los ejes en 0 sino a la hora de empezar a cortar la máquina primero buscará el punto 0 y luego empezará a cortar.

24- para poder desplazar los ejes manualmente apretaremos tab y nos saldra una herramienta donde podremos desplazar los ejes de forma manual.

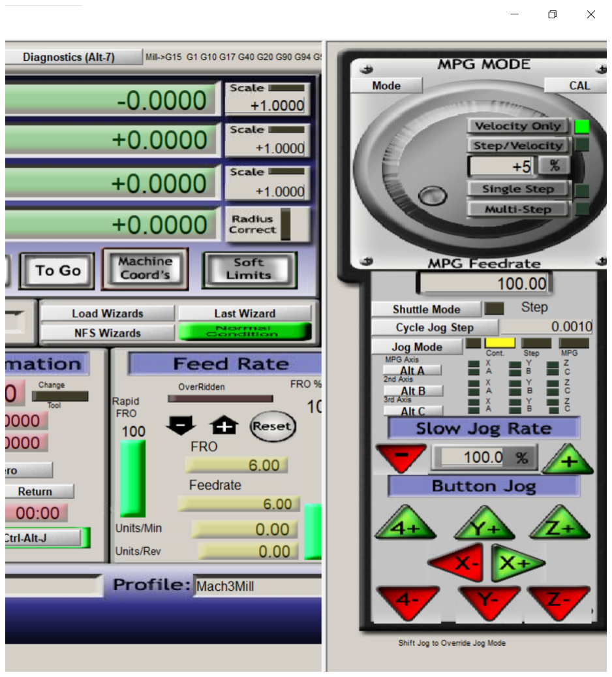
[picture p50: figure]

25- con esta guia ya conoces lo necesario para poder pasar una imagen a cam y luego cortar, se recomiendo igualmente leer tanto la documentación que se encuentra en github , donde subimos los manuales de lazycam y mach3 para un mayor conocimiento y también los videos tutoriales que al igual que la documentación estan subidos a github.

26- A continuación dejo el link de github:

https://github.com/impatrq/cnc_drawing_machine

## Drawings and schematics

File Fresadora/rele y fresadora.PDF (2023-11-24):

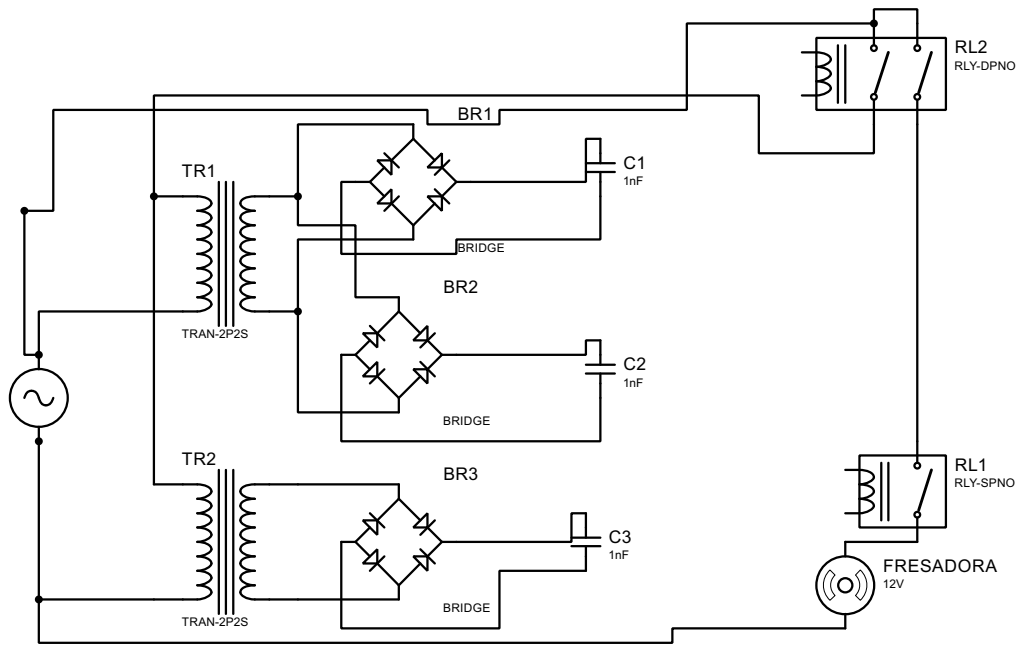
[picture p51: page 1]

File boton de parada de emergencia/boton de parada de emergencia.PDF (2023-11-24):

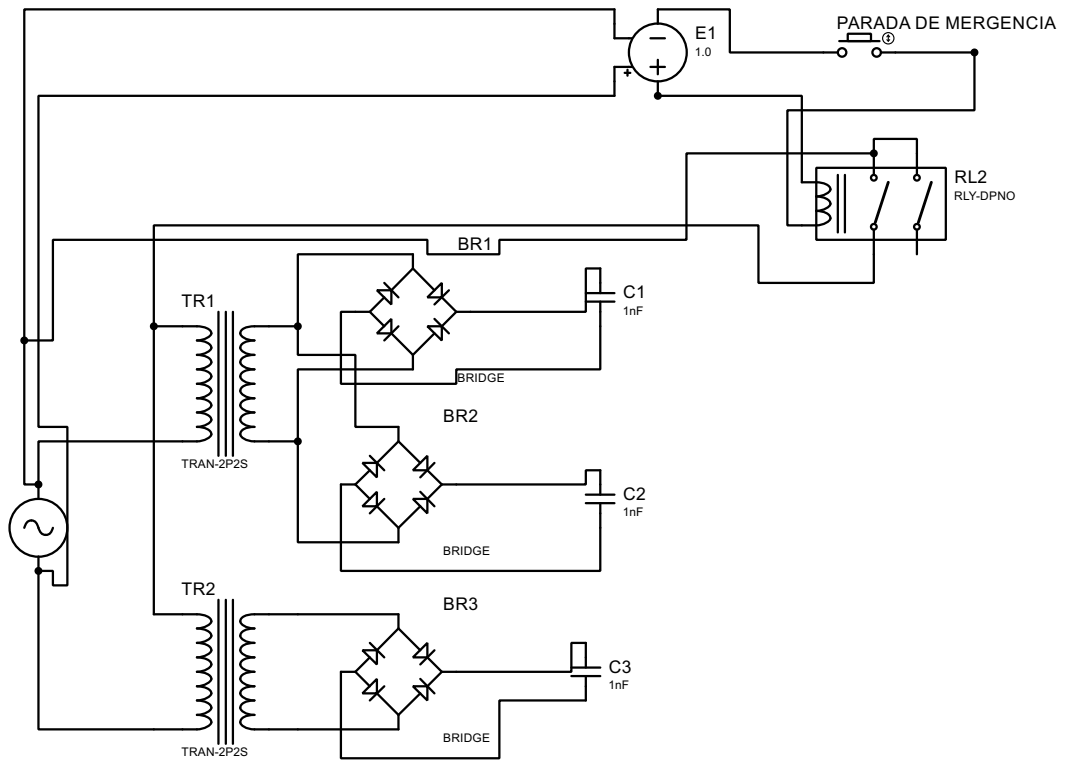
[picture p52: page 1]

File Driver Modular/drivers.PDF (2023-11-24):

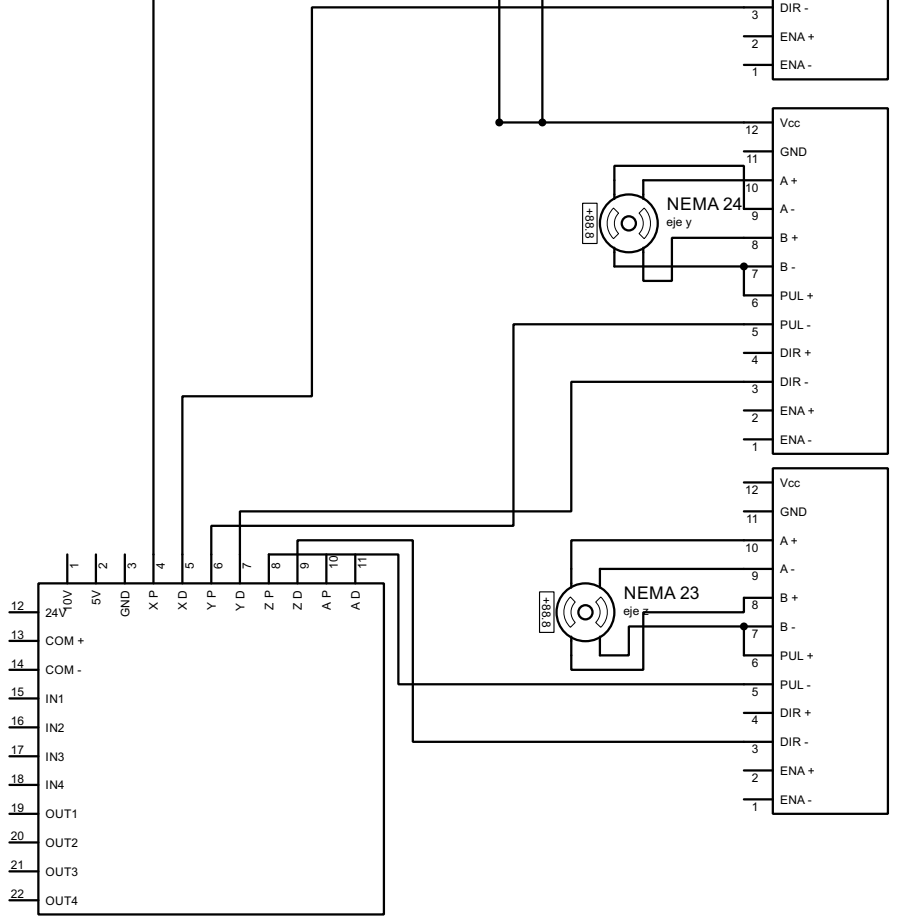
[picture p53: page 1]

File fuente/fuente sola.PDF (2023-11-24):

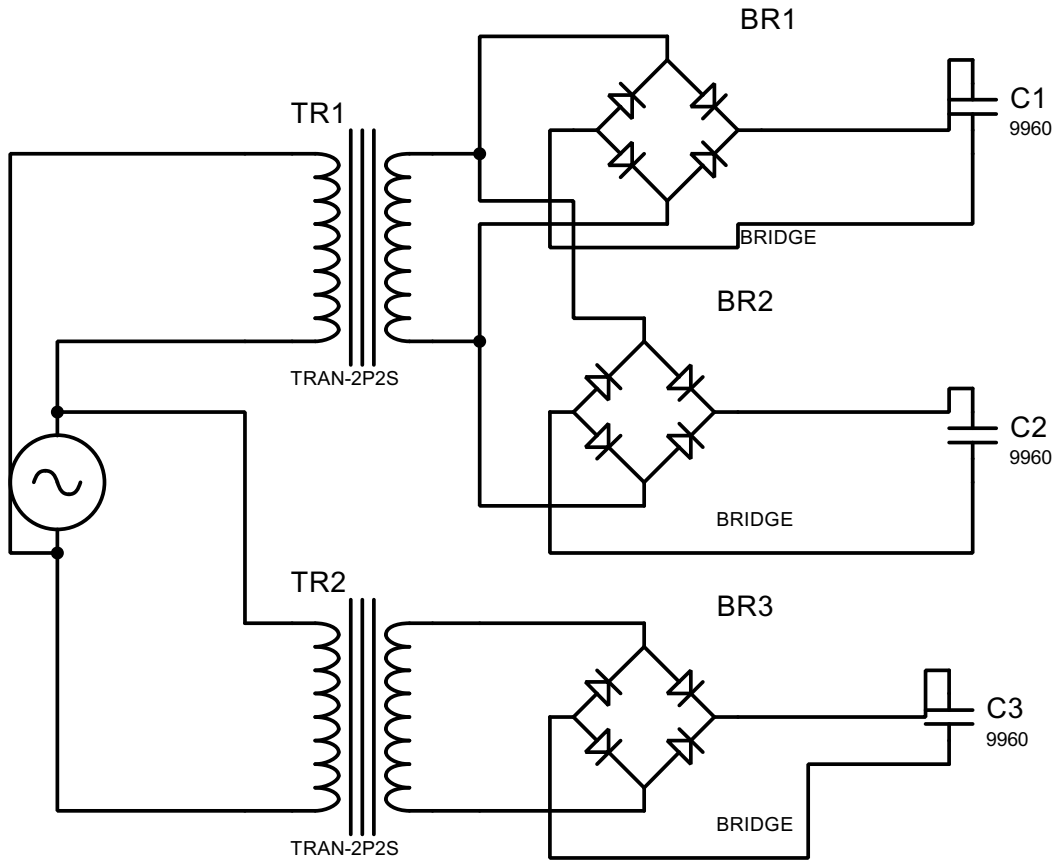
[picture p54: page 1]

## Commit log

2023-11-06 Create Circuitos
2023-11-06 Create Circuito
2023-11-14 doc:dibujos dxf
    [Escudo_de_Racing_Club.dxf, Escudo_del_Club_Atlético_Independiente.dxf, Roma-Logo-2013.dxf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]
2023-11-15 Create Restaruracion
    Carpeta para describir los cambios esteticos y practicos realizados en la maquina para una mejor funcion
2023-11-15 feat: crear directorio de restauraciones
2023-11-15 chore: eliminar carpeta de prueba
2023-11-15 docs: Proteccion de los rieles
2023-11-17 feat: agregado de links de instalacion mach 3
2023-11-17 feat: agregado de link de instalacion de Inkscape
2023-11-17 feat: agregado de tutoriales para mach3
2023-11-17 feat: agregado de links a tutoriales de lazycam
2023-11-17 feat: agregado links a tutoriales de inkscape
2023-11-17 fix: modificar ruta de enlaces
2023-11-21 feat: agregar ultimos dibujos dxf realizados
    [goku.dxf, lisa.dxf, logotunellllll.dxf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]
2023-11-21 feat: agregar imagen de drivers
2023-11-21 feat: subir imagen de calibracion eje y
2023-11-21 feat: subir imagen configuracion de pines de motores en mach3
2023-11-21 feat: subir imagen de configuracion de pines de la fresadora mach3
2023-11-21 feat: subir imagen de otros ajustes de la fresadora
2023-11-22 feat: agregar carpeta circuitos
2023-11-22 fist: Agregar Carpeta de Campo
2023-11-22 fist: agregar Datasheet Driver Motor
2023-11-23 feat: Agregar Carpeta de Campo
2023-11-23 feat: cambiar nombre de carpetas y acomodo
    [Escudo_de_Racing_Club.dxf, Escudo_del_Club_Atlético_Independiente.dxf, Roma-Logo-2013.dxf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]
2023-11-23 feat: Agregar datasheet del motor NEMA 24
2023-11-23 feat: agregar datasheet de la fuente de 24V
2023-11-23 Fis Facturacion/Captura de pantalla 2023-11-21 153033.png
2023-11-23 Create Esquema de circuito del CNC
2023-11-23 Add file 3 fotos del circuito de alimentacion
2023-11-23 Add file Esquema de la placa de interfaz
2023-11-23 add file Diagrama de la estructura del motor nema
2023-11-23 add file Carpeta de campo (arregalada)
2023-11-23 add file 3 fotos de la base del CNC
2023-11-23 add 3 fotos de la Base del CNC
2023-11-24 feat:agregar foto de la fuente
2023-11-24 feat:agregar foto de fuente
2023-11-24 feat:agregar proteus de la interfaz
2023-11-24 feat:foto de la fresa
2023-11-24 feat:agregar foto de fresa para grabar
2023-11-24 feat.agregar foto del motor eje y
2023-11-24 feat:agregar foto del driver eje y
2023-11-24 fix: Delete Restauración/Crcasa_eje_x/Captura de pantalla 2023-11-15 112a448.png
2023-11-24 fix: Delete Restauración/Carcasa_eje_x/Captura de pantalla 2023-11-15 124000.png
2023-11-24 fix: Delete Restauración/Carcasa_eje_x/Captura de pantalla 2023-11-15 124246.png
2023-11-24 fix: Delete Restauración/Carcasa_eje_x/Captura de pantalla 2023-11-15 125742.png
2023-11-24 docs: agregar placas posteriores de rieles
2023-11-24 fix: Delete Restauración/Proteccion de Rieles/Captura de pantalla 2023-11-15 125341.png
2023-11-24 fix: Delete Restauración/Proteccion de Rieles/Captura de pantalla 2023-11-15 125200.png
2023-11-24 fix: Delete Restauración/Proteccion de Rieles/Captura de pantalla 2023-11-15 125227.png
2023-11-24 docs: agregar carcasa protectora motor eje x
2023-11-24 docs: agregar carcasa de eje x restaurada
2023-11-24 fix: Delete Restauración/Proteccion de Rieles/Captura de pantalla 2023-11-15 125258.png
2023-11-24 feat:foto del driver del eje z
2023-11-24 docs: agregar placas posteriores de rieles nuevas
2023-11-24 docs: agregar placas interiores de rieles
2023-11-24 docs: agregar placas frontales de rieles
2023-11-24 feat:foto del motor e impresion 3d
